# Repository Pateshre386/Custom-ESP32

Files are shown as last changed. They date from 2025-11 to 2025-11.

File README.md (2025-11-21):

# Custom ESP32-S3 Development Board
**EDA Tool:** Altium Designer

## Project Overview
A custom 4-layer development board based on the ESP32-S3 Mini. 
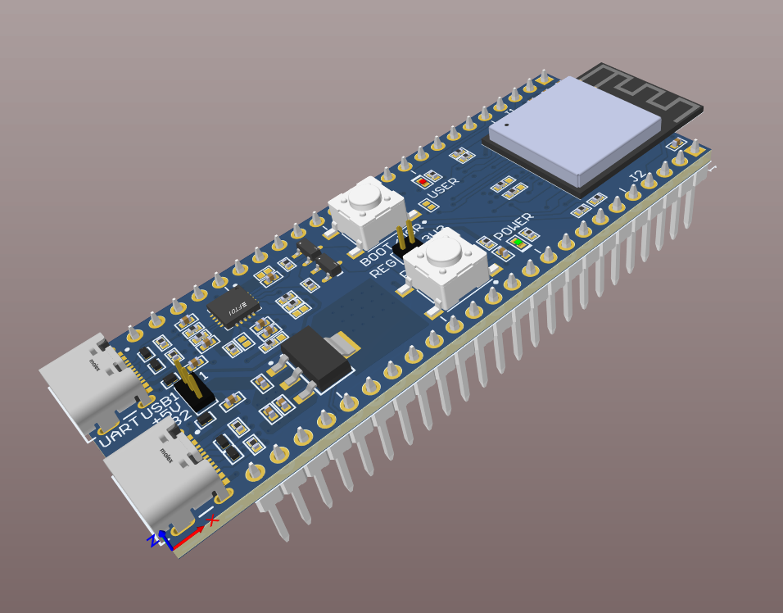
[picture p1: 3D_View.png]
Board 3D View


## Key Features
* **MCU:** ESP32-S3 Mini (Dual-core XTensa LX7, 240 MHz)
* **Power:** 5V USB-C input with 3.3V/800mA LDO regulation.
* **Connectivity:** Native USB-C JTAG/Serial debugging + UART Bridge.
* **PCB Stackup:** 4-Layer (Sig / Gnd / Pwr / Sig) 
Board 2D View

## Design View
Output Files available in the (Project Outputs for ESP32 With USB C/Sent To Production/Gerber.zip) folder.

## Fabrication
* Manufactured by JLCPCB.
* Design Rules: 6mil trace / 6mil space.
* Via Sizes: 0.3mm hole / 0.6mm pad.

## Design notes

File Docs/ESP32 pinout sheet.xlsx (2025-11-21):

1 | GND_01
2 | GND_02
3 | 3V3
4 | GPIO0/RTC_GPIO0
5 | GPIO1/RTC_GPIO1/TOUCH1/ADC1_CH0
6 | GPIO2/RTC_GPIO2/TOUCH2/ADC1_CH1
7 | GPIO3/RTC_GPIO3/TOUCH3/ADC1_CH2
8 | GPIO4/RTC_GPIO4/TOUCH4/ADC1_CH3
9 | GPIO5/RTC_GPIO5/TOUCH5/ADC1_CH4
10 | GPIO6/RTC_GPIO6/TOUCH6/ADC1_CH5
11 | GPIO7/RTC_GPIO7/TOUCH7/ADC1_CH6
12 | GPIO8/RTC_GPIO8/TOUCH8/ADC1_CH7/SUBSPICS1
13 | GPIO9/RTC_GPIO9/TOUCH9/ADC1_CH8/FSPIHD/SUBSPIHD
14 | GPIO10/RTC_GPIO10/TOUCH10/ADC1_CH9/FSPICS0/FSPIIO4/SUBSPICS0
15 | GPIO11/RTC_GPIO11/TOUCH11/ADC2_CH0/FSPID/FSPIIO5/SUBSPID
16 | GPIO12/RTC_GPIO12/TOUCH12/ADC2_CH1/FSPICLK/FSPIIO6/SUBSPICLK
17 | GPIO13/RTC_GPIO13/TOUCH13/ADC2_CH2/FSPIQ/FSPIIO7/SUBSPIQ
18 | GPIO14/RTC_GPIO14/TOUCH14/ADC2_CH3/FSPIWP/FSPIDQS/SUBSPIWP
19 | GPIO15/RTC_GPIO15/U0RTS/ADC2_CH4/XTAL_32K_P
20 | GPIO16/RTC_GPIO16/U0CTS/ADC2_CH5/XTAL_32K_N
21 | GPIO17/RTC_GPIO17/U1TXD/ADC2_CH6
22 | GPIO18/RTC_GPIO18/U1RXD/ADC2_CH7/CLK_OUT3
23 | USB_D-/RTC_GPIO19/GPIO19/U1RTS/ADC2_CH8/CLK_OUT2
24 | USB_D+/RTC_GPIO20/GPIO20/U1CTS/ADC2_CH9/CLK_OUT1
25 | GPIO21/RTC_GPIO21
26 | GPIO26/SPICS1
27 | GPIO47/SPICLK_P_DIFF/SUBSPICLK_P_DIFF
28 | GPIO33/SPIIO4/FSPIHD/SUBSPIHD
29 | GPIO34/SPIIO5/FSPICS0/SUBSPICS0
30 | GPIO48/SPICLK_N_DIFF/SUBSPICLK_N_DIFF
31 | GPIO35/SPIIO6/FSPID/SUBSPID
32 | GPIO36/SPIIO7/FSPICLK/SUBSPICLK
33 | GPIO37/SPIDQS/FSPIQ/SUBSPIQ
34 | GPIO38/FSPIWP/SUBSPIWP
35 | MTCK/GPIO39/CLK_OUT3/SUBSPICS1
36 | MTDO/GPIO40/CLK_OUT2
37 | MTDI/GPIO41/CLK_OUT1
38 | MTMS/GPIO42
39 | U0TXD/GPIO43/CLK_OUT1
40 | U0RXD/GPIO44/CLK_OUT2
41 | GPIO45
42 | GND
43 | GND
44 | GPIO46
45 | EN
46 | GND_46
47 | GND_47
48 | GND_48
49 | GND_49
50 | GND_50
51 | GND_51
52 | GND_52
53 | GND_53
54 | GND_54
55 | GND_55
56 | GND_56
57 | GND_57
58 | GND_58
59 | GND_59
60 | GND_60
61 | GND_61
62 | GND_62
63 | GND_63
64 | GND_64
65 | GND_65
66 | GND_66
67 | GND_67
68 | GND_68
69 | GND_69
70 | GND_70
71 | GND_71
72 | GND_72
73 | GND_73

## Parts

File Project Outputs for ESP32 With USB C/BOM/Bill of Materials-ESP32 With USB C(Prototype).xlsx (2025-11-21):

Comment | Description | Designator | Footprint | LibRef | Quantity | LCSC Part Number | Manufacturer | Manufacturer Lifecycle Status | Supplier | Supplier Part Number
100nF, 50V | Ceramic Capacitor, Multilayer, Ceramic, 50V, 10% +Tol, 10% -Tol, X7R, +-15% TC, 100nF, Surface Mount, 0402 inch | C1, C3, C4, C6, C7, C8, C9, C10, C15 | CAPC1005X65N | CL05B104KB5NNNC | 9 | C960916 | Samsung Electro-Mechanics |  | DigiKey | 1276-CL05B104KB5NNNCCT-ND
4u7, 16V | CAP CER 4.7UF 16V X5R 0402 | C2, C11 | CAPC1005X65N | CL05A475MO5NUNC | 2 | C318563 | Samsung Electro-Mechanics |  | DigiKey | 1276-6836-1-ND
10uf, 10V | CAP CER 10UF 10V X5R 0402 | C12, C13, C14 | CAPC1005X65N | CL05A106MP8NUB8 | 3 | C307415 | Samsung Electro-Mechanics |  | DigiKey | 1276-6830-1-ND
1uF, 35V | CAP CER 1UF 35V X5R 0402 | C16 | CAPC1005X65N | CL05A105KL5NRNC | 1 | C307413 | Samsung Electro-Mechanics |  | DigiKey | 1276-6796-1-ND
GREEN | LED YLW-GRN 0402 SMD | D1 | LED0402G | VLMG1500-GS08 | 1 | C511404 | Vishay |  | DigiKey | VLMG1500-GS08CT-ND
RED | LED RED 0402 SMD | D2 | LED0402R | VLMS1500-GS08 | 1 | C511370 | Vishay |  | DigiKey | VLMS1500-GS08CT-ND
AQ3045-01ETG | TVS DIODE 5.3VWM 12VC SOD882 | D3, D4, D5, D6, D7, D8 | SOD882 | AQ3045-01ETG | 6 | C3710326 | Littelfuse |  | DigiKey | F9321CT-ND
22-28-4245 | CONN HEADER VERT 24POS 2.54MM | J1, J2 | HDR_1X24_2.54MM | 22-28-4245 | 2 | C7145888 | Molex | ACTIVE | DigiKey | 900-0022284245-ND
217179-0001 | CONN RCP USB2.0 TYP C 24P SMD RA | J3, J4 | FP-2171790001-MFG | 217179-0001 | 2 | C3197684 | Molex |  | DigiKey | 900-2171790001DKR-ND
FTS-102-01-F-S | CONN HEADER VERT 2POS 1.27MM | J5 | HDR_1X2_1.27MM | FTS-102-01-F-S | 1 | C6045317 | Samtec | PRODUCTION | DigiKey | SAM15176-ND
FTS-103-01-F-S | CONN HEADER VERT 3POS 1.27MM | J6 | HDR_1X3_1.27MM | FTS-103-01-F-S | 1 | C3333578 | Samtec | PRODUCTION | DigiKey | 612-FTS-103-01-F-S-ND
M50-1920005 | CONN SHUNT 1.27MM RED | LINK1, LINK2 |  | M50-1920005 | 2 | C6985646 | Harwin |  | DigiKey | 952-1727-ND
SS8050-G | TRANS NPN 25V 1.5A SOT-23-3 | Q1, Q2 | FP-SS8050-G-IPC_B | SS8050-G | 2 | C164886 | Comchip |  | DigiKey | 641-1790-1-ND
0R | RES 0 OHM JUMPER 1/16W 0402 | R1, R8, R19, R21, R23, R24 | RESC1005X37N | RC0402JR-070RL | 6 | C60485 | Yageo Group |  | DigiKey | 311-0.0JRCT-ND
27R | RES 27 OHM 1% 1/16W 0402 | R4, R7, R18, R22 | RESC1005X37N | RC0402FR-0727RL | 4 | C138021 | Yageo Group |  | DigiKey | YAG3086CT-ND
1K | RES 1K OHM 1% 1/16W 0402 | R5, R6 | RESC1005X37N | RC0402FR-071KL | 2 | C106235 | Yageo Group |  | DigiKey | 311-1.00KLRCT-ND
4k7, | RES 4.7K OHM 1% 1/16W 0402 | R10 | RESC1005X37N | RC0402FR-074K7L | 1 | C105871 | Yageo Group |  | DigiKey | 311-4.7KLRCT-ND
5K1 | RES SMD 5.1K OHM 1% 1/16W 0402 | R11, R12, R14, R15 | RESC1005X37N | AC0402FR-075K1L | 4 | C144745 | Yageo Group |  | DigiKey | YAG3503CT-ND
10K | RES 10K OHM 1% 1/16W 0402 | R13, R16, R17, R20 | RESC1005X37N | AF0402FR-0710KL | 4 | C723353 | Yageo Group |  | DigiKey | 13-AF0402FR-0710KLCT-ND
Tactile Switch 1 | SWITCH TACTILE SPST-NO 0.05A 12V | SW1, SW2 | SWITCH_43SMTR92LFS | Y97HT23B2EAFP | 2 | C22043769 | C&K Components |  | DigiKey | CKN9112CT-ND
ESP32-S3-MINI-1-N8 | SMD module, ESP32-S3FN8, 8 MB SPI flash, PCB antenna | U1 | XCVR_ESP32-S3-MINI-1-N8 | ESP32-S3-MINI-1-N8 | 1 | C2913206 | Espressif Systems |  | DigiKey | 5407-ESP32-S3-MINI-1-N8CT-ND
FT231XQ-R | IC USB SERIAL FULL UART 20QFN | U2 | FP-QFN-20-IPC_B | FT231XQ-R | 1 | C132159 | FTDI |  | DigiKey | 768-1128-1-ND
TL1963A-33DCYR | IC REG LIN 3.3V 1.5A SOT-223-4 | U3 | DCY0004A_N | TL1963A-33DCYR | 1 | C181262 | Texas Instruments | ACTIVE | DigiKey | 296-24897-1-ND

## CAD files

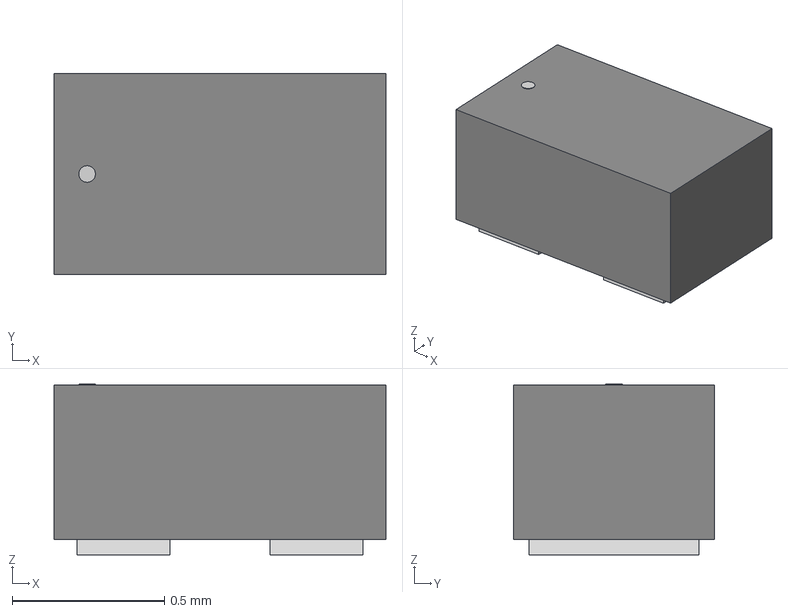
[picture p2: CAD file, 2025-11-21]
Docs/AQ3045_01ETG/Altium/AQ3045-01ETG/RTVS_SOD882_LTF.step
1.09 x 0.66 x 0.561 mm

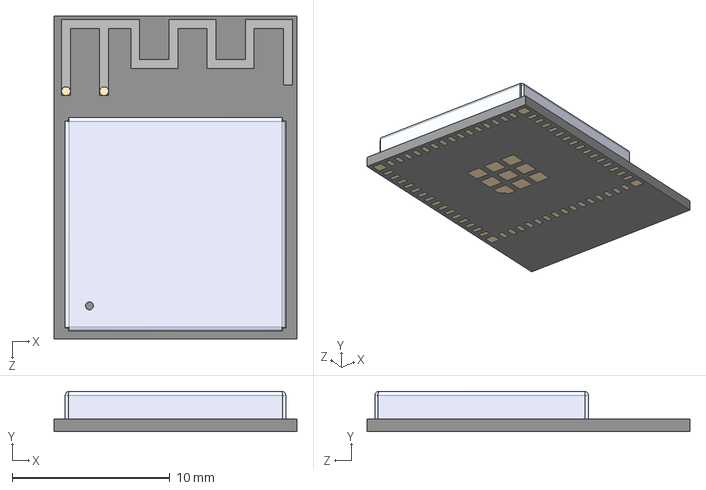
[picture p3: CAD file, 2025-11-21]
Docs/ESP32-S3-MINI-1-N8--3DModel-STEP-510211.STEP
15.4 x 2.55 x 20.5 mm

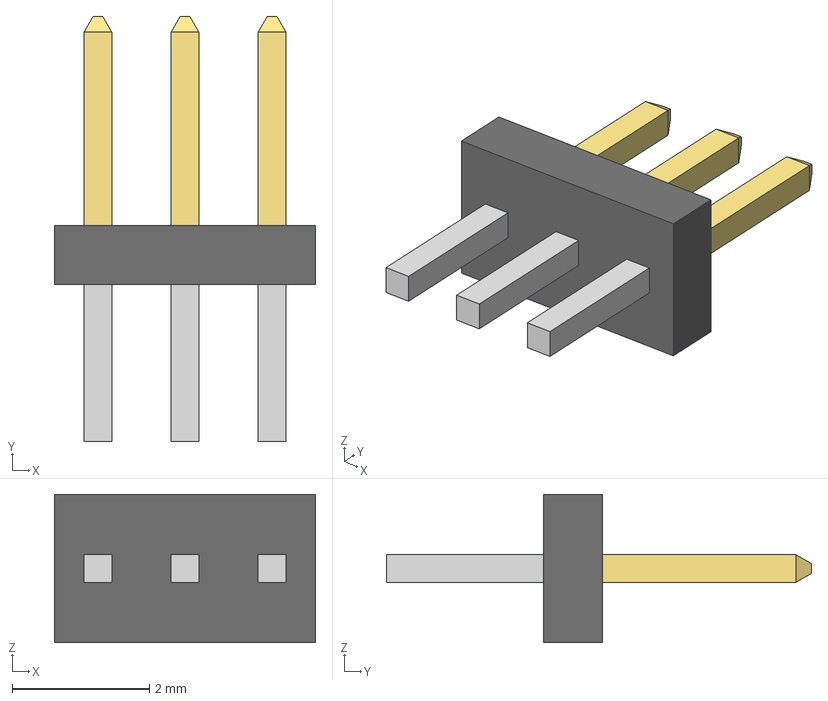
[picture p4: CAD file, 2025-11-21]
Docs/PARTserver22025111406163731664803d0b6156e/FTS-103-01-F-S.stp
3.81 x 6.20 x 2.16 mm
FTS-103-01-F-S_body
FTS-103-01-F-S_pins1
FTS-103-01-F-S_pins2

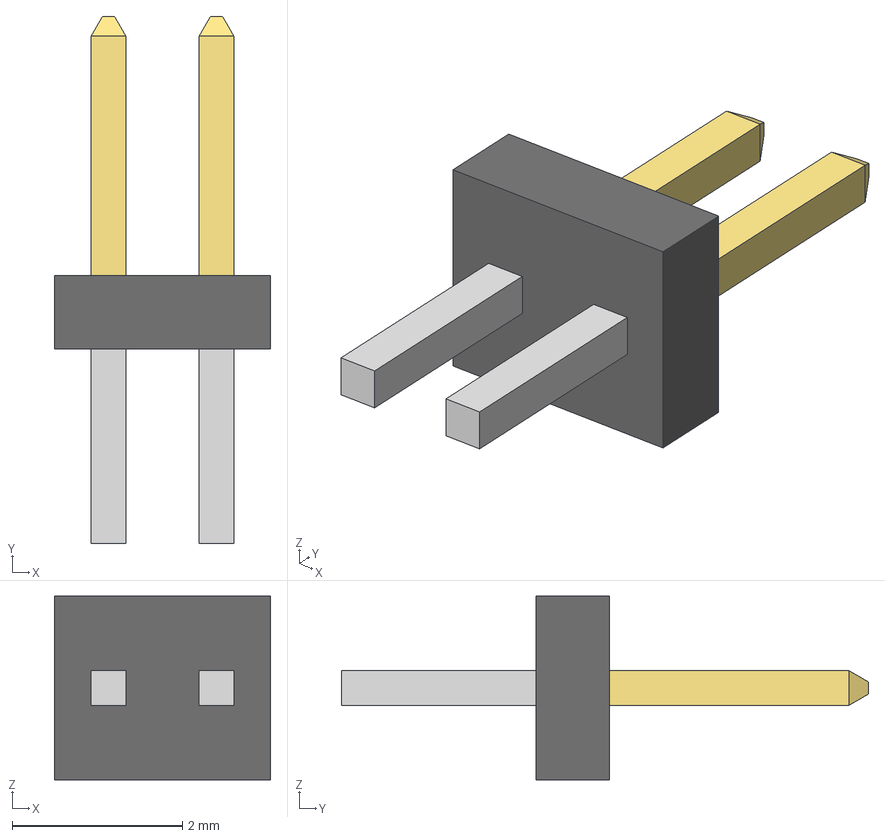
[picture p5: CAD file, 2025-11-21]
Docs/PARTserver22025111406244236100410d0b6156e/FTS-102-01-F-S.stp
2.54 x 6.20 x 2.16 mm
FTS-102-01-F-S_body
FTS-102-01-F-S_pins1
FTS-102-01-F-S_pins2

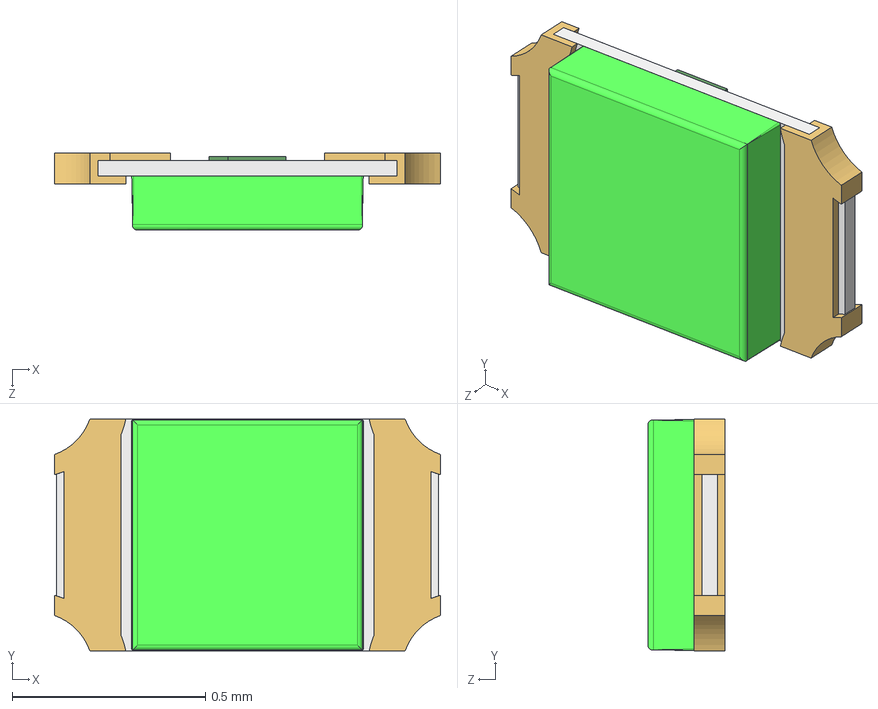
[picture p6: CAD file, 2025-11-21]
Docs/User Library-LED_1006_G/User Library-LED_1006_G.STEP
1.00 x 0.6 x 0.2 mm
Grⁿn
Cut005_(Mirror_#1)

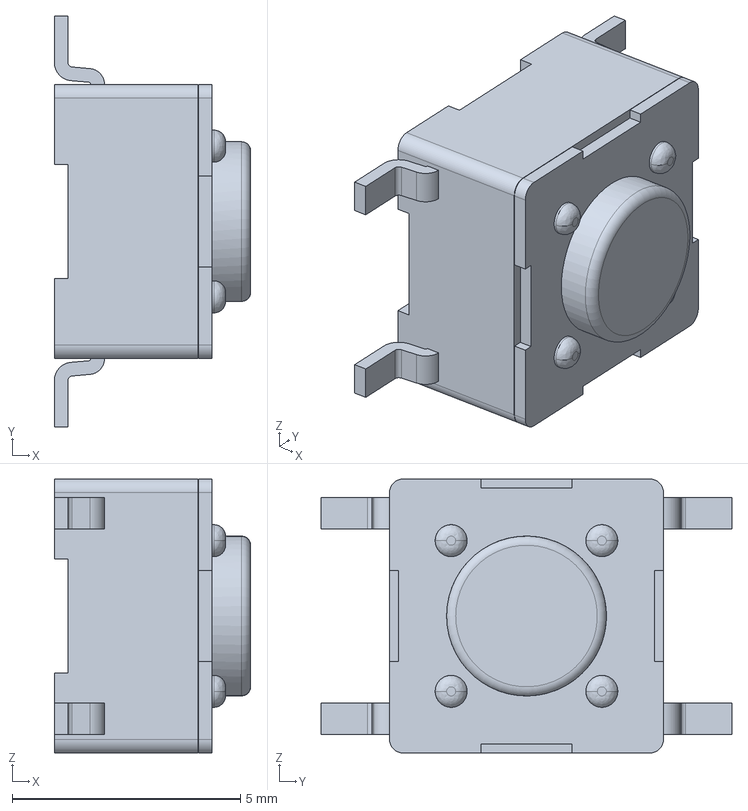
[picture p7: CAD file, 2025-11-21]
Docs/Y97HT23B2EAFP/PTS645SM43SMTR92LFS.stp
4.30 x 9.00 x 6.00 mm

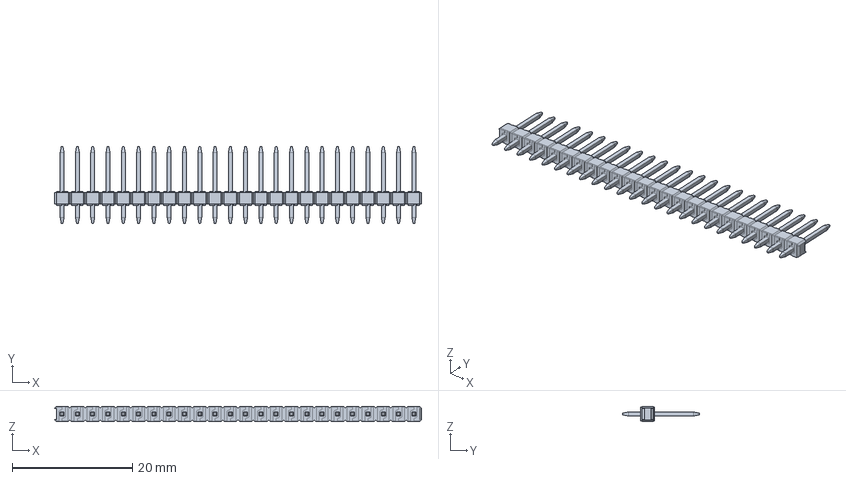
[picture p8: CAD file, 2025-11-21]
Docs/173971094-659-0022284245/0022284245.stp
61.0 x 12.8 x 2.49 mm

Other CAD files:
Docs/AQ3045_01ETG/RTVS_SOD882_LTF.step
Docs/User Library-LED_1006_R/User Library-LED_1006_R.STEP

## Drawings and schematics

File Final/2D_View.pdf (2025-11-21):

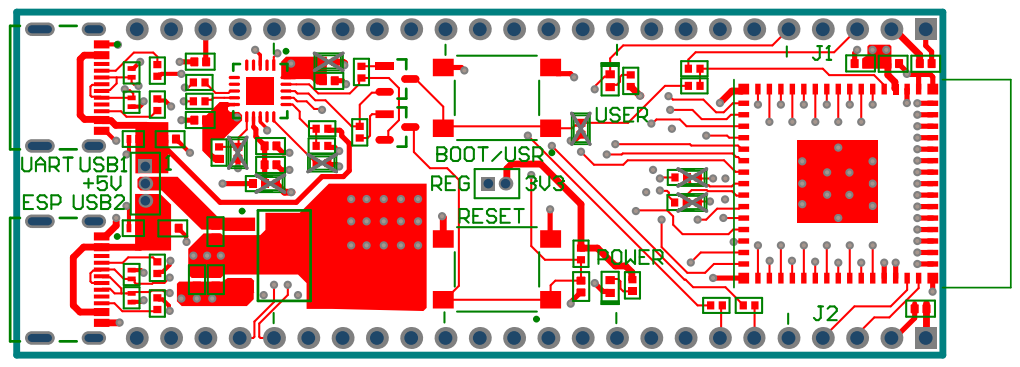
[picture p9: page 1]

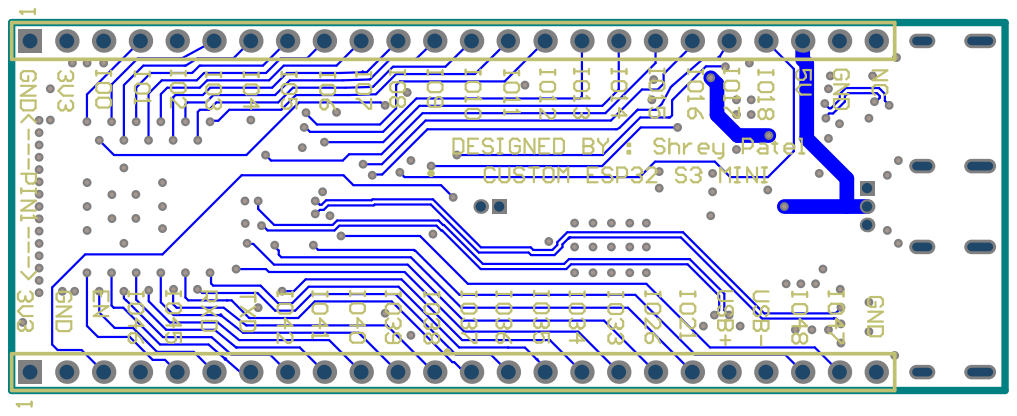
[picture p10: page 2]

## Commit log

2025-11-21 Rename Board to Check.pdf to 2D_View.pdf
2025-11-21 Add README for custom ESP32-S3 development board
    Added detailed project overview and key features for the custom ESP32-S3 development board.
2025-11-21 Revise PCB stackup and hardware output link
    Updated PCB stackup description and corrected link to hardware output files.
2025-11-21 Update README to include image for Board 2D View

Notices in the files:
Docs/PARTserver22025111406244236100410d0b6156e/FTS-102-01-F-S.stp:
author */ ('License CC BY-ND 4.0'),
